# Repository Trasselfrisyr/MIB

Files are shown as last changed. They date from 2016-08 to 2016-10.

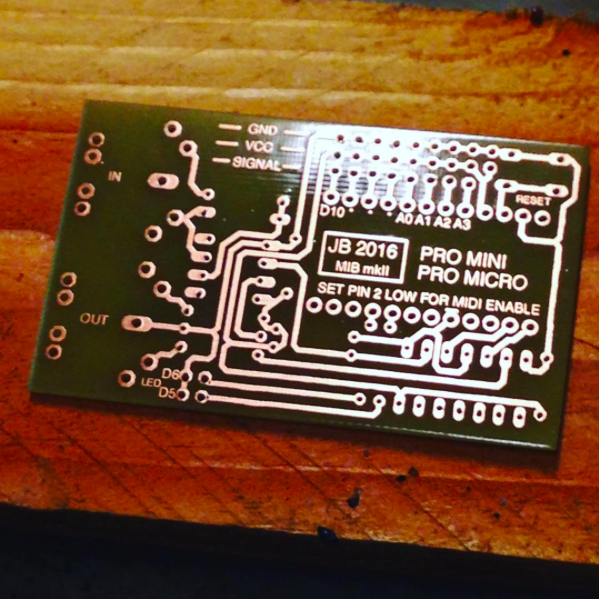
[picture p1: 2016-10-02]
MIB-board-mkII/MIBmkII-2.png

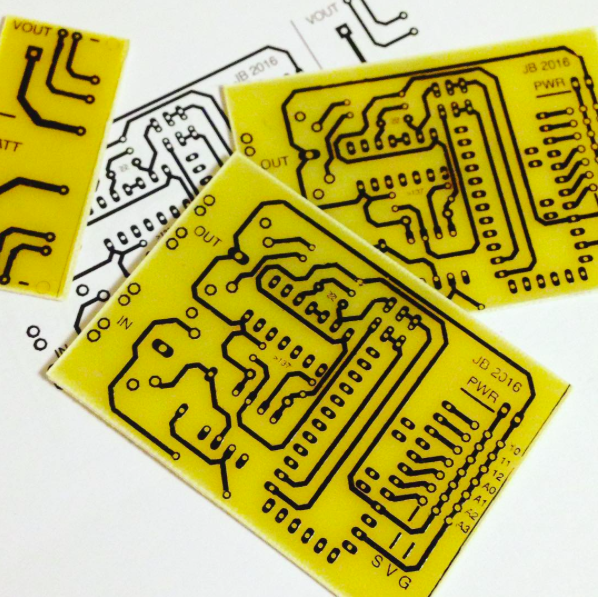
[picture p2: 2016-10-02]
MIB-board-mkI/MIBmkI-2.png

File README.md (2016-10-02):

# MIB
MIDI Injector Box, merge controller data to MIDI

Makes use of the the FortySevenEffects Arduino MIDI Library, so make sure you've got that one.

For hardware, you can build the board from plans in the MIB-board folders to use together with a Pro Mini or use any MIDI shield together with an Arduino Uno.

Breath-Injector.ino - adds breath controller data to DIN-5 MIDI from a keyboard, great for creating a MIDI melodica. For use with breath controller synth patches responding to CC#2 (breath). Can easily be changed to send other CC data like volume or mod wheel by changing the CC_Number definition in the code.

Breath-Injector-ProMicroArcore.ino - version of breath injector above, using a Pro Micro and the Arcore arduino core for USB MIDI support. This version also transmits the breath data to USB. Made for the MIB mkII board.

Volume-Injector.ino - adds volume cc data. Build your own MIDI volume pedal perhaps?

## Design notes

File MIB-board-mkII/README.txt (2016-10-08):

General board for MIB projects. MIDI in (via optocoupler)
and out (via buffer), GVS pin groups for easy connection
of potentiometers, switches and LEDs to A0-A3 and digital
pins 10 through 13 on Pro Mini. Pins 10, 15, 14 and 15 on
Pro Micro. LED connectors with resistors on pins 5 and 6.
Board power is supplied via the USB port on the Pro Micro
and by supplying regulated 5V DC power to VCC/GND if using
Pro Mini. A micro USB board connected to the dedicated pins
on the GVS strip closest to the reset button, and a USB power
adapter is a good way to do this.

Component list:

1x Arduino Pro Mini or Pro Micro (socket recommended)
1x 6N138 or 6N139 optocoupler, DIP (socket recommended)
1x 74HC125 buffer, negative enable, DIP (socket recommended)
1x 1N4148 diode, mind the orientation
2x 2K2 resistor
5x 220 ohm resistor
1x 10K resistor
2x 100nF ceramic capacitor
2x PCB mount DIN-5 MIDI PCB connector
1x Tact Switch 6x6 mm
Breakable pin headers, black, red, white/yellow for GVS
Pin headers in black and green or blue for LED connectors,
and black headers for the Arduino, to plug it into the socket
(for a snug fit agains the socket, mount the header upside
down and cut the excess off the top after soldering.)

Notes:
The board uses the 74HC125 to disconnect the MIDI circuits for
problem free reprogramming of the Pro Mini. To enable the MIDI
connection, you must set pin 2 low in the Arduino sketch.

pinMode(2,OUTPUT);
digitalWrite(2,LOW); // set pin 2 low to enable DIN MIDI

This is if you write your own code. In the MIB code projects
available on github, this is already done.

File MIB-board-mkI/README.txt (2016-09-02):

General board for MIB projects. MIDI in (via optocoupler)
and out (via optional buffer), GVS pin groups for easy connection
of potentiometers, switches and LEDs to A0-A3 and digital pins
10, 11 and 12. Optional battery power supply part with soldered
in charge/step-up board.

Component list:

1x Arduino Pro Mini
1x 6N137, 6N138 or 6N139 optocoupler, DIP (OK2)
1x 74LS14 buffer/inverter, DIP, optional (IC1)
1x 1N4148 diode, mind the orientation (D1)
2x 2K2 resistor (if 6N137, just one) (R3, R5*)
3x 220 ohm resistor (R1, R2, R4)
2x PCB mount DIN-5 MIDI PCB connector (X1, X2)
1x Slide switch DPDT (2.54 mm pin separation) (S1)
Breakable pin headers, black, red, white for GVS

Optional power circuit:

Battery holder 16340
Li-Ion battery 3.7V 16340
All-in-one charge and step-up board (r.ebay.com/uWUNOm)

VOUT +/- connects to PWR +/- of main circuit via a switch.
VIN +/- connects to panel mount power jack for 5V input.

Notes for assembling:

If the 74LS14 DIP is installed, the jumper pads marked <<>> are
left unconnected. If DIP is not installed, bridge the pads with
a jumper to connect the TX line to the output.

If the optocoupler selected for the build is a 6N137, the 2K2
resistor where PCB is marked >137 (R5) is omitted.

The slide switch on the board is for disconnecting the TX and RX
lines when uploading new programs to the Arduino. If you can't find
a DPDT switch that fits, you could go with single slide switches or
probably DIP switches too. Or jumpers.

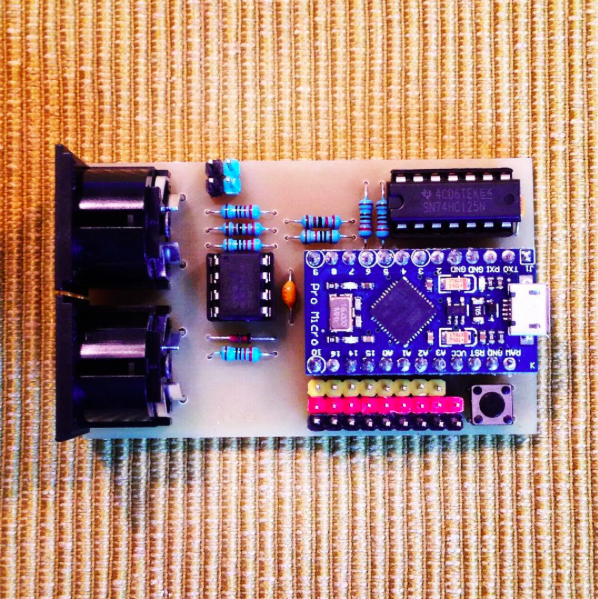
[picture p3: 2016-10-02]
MIB-board-mkII/MIBmkII-1.png

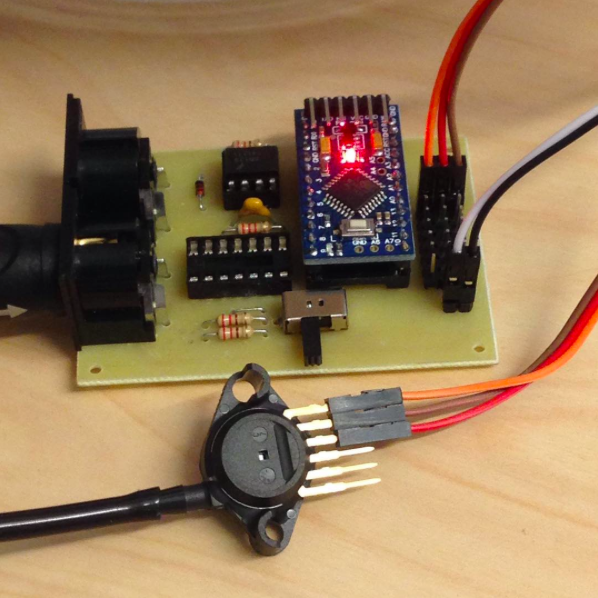
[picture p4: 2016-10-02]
MIB-board-mkI/MIBmkI-1.png

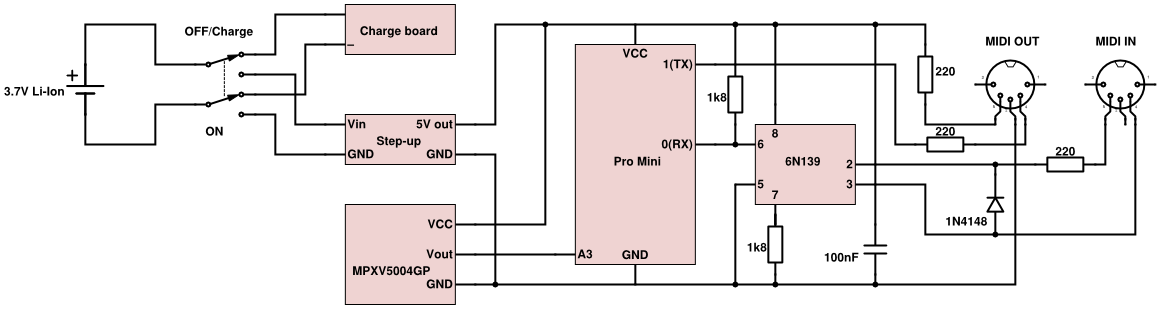
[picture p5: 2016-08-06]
Breath-Injector/Breath-Injector.png

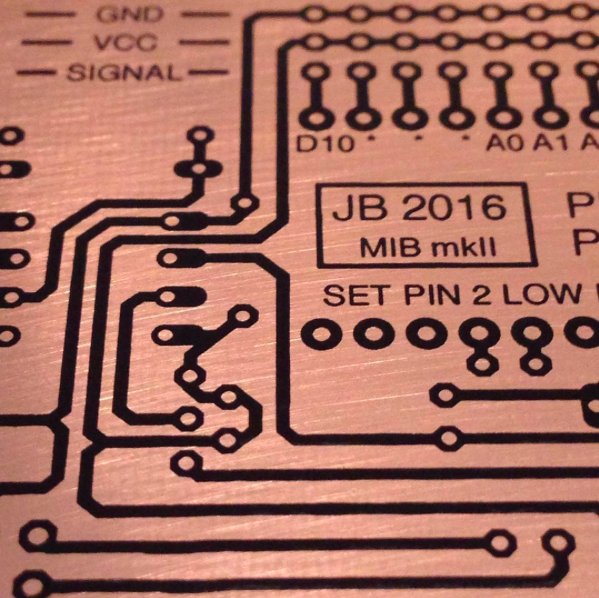
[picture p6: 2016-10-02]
MIB-board-mkII/MIBmkII-3.png

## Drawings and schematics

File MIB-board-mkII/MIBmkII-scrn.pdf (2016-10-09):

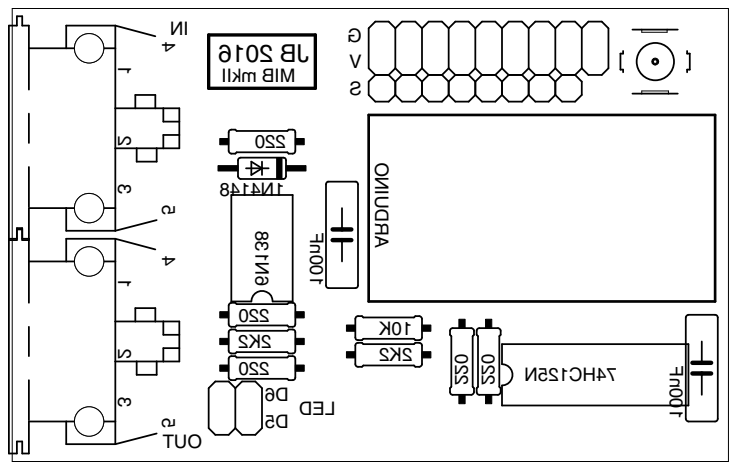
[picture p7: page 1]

II k mBI M 6102 BJDEL NI TUO 6 D5 D GVS 100nF 8414 N1 N521 CH47 6N138 022 022 022 2K2 2K2 ARDUINO K01 100nF220 2202 4 5 3 1 2 4 5 3 1

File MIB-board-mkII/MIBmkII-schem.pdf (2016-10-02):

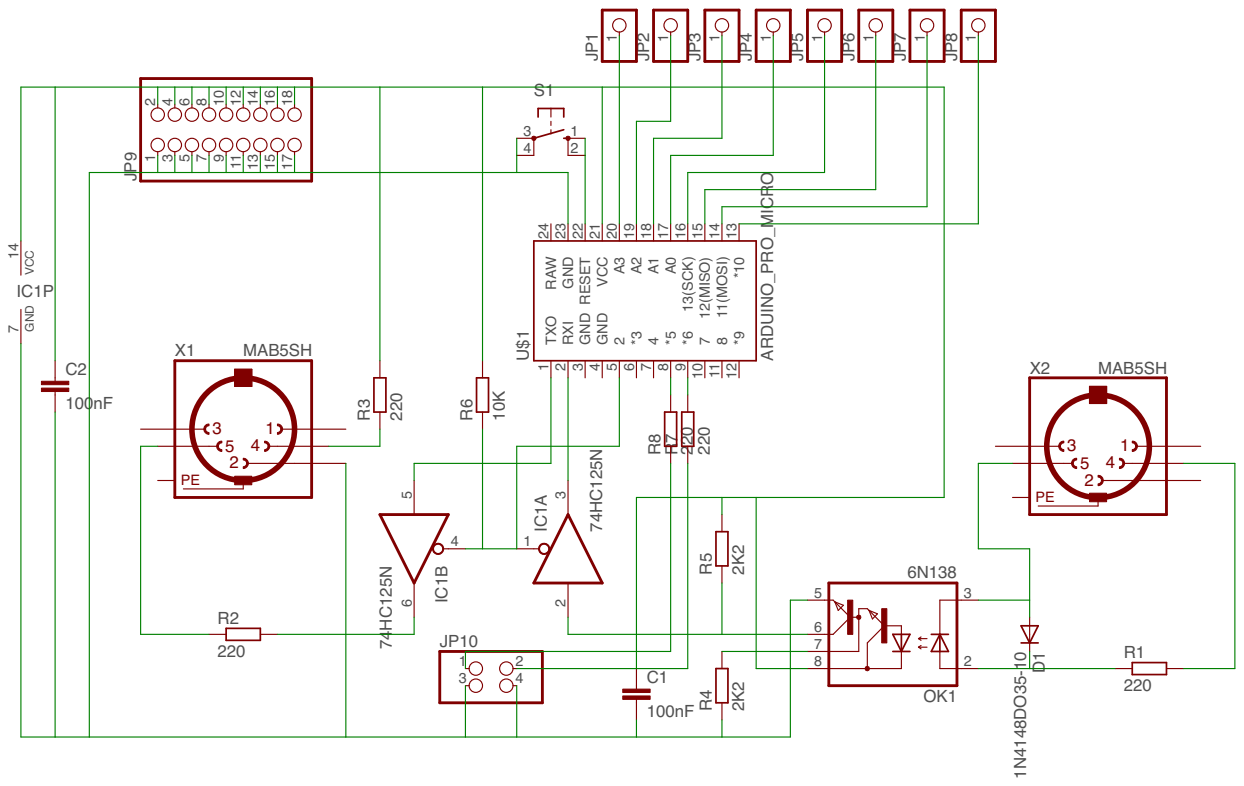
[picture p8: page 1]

ARDUINO_PRO_MICRO 74HC125N 74HC125N6N138 220 220 220 2K2 2K2 100nF 1N4148DO35-10 MAB5SH MAB5SH 10K100nF 220 220 U$12 5 *3 6 4 7 *5 8 *6 9 7 10 8 11 *9 12 *10 13 11(MOSI) 14 12(MISO) 15 13(SCK) 16 A0 17 A1 18 A2 19 A3 20 GND 4 GND 23 RAW 24 GND 3 RESET 22 RXI 2 TXO 1 VCC 21 IC1A 1 2 3 IC1B 4 5 6 IC1PGND VCC 7 14 OK1 23 7856 R1 R2 R3 R4 R5 C1 D1 X1 X2 JP11 JP21 JP31 JP41 JP51 JP61 JP71 JP81 JP91 2 3 4 5 6 7 8 9 10 11 12 13 14 15 16 17 18 R6 C2 R7 JP101 2 3 4 R8 S1 3 1 4 2 1 2 3 5 4 PE 1 2 3 5 4 PE

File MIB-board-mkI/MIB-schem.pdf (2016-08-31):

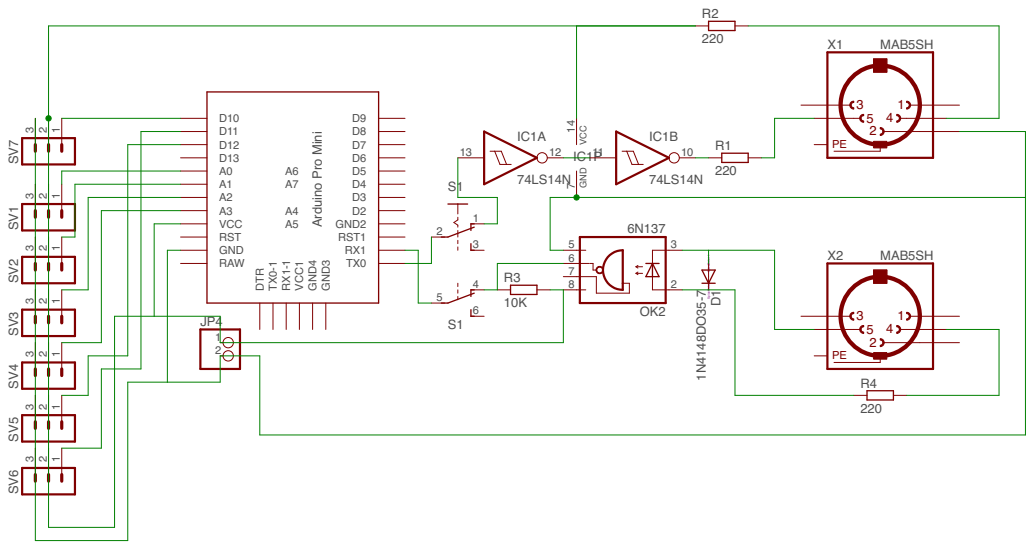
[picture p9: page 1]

SpiceOrder 1 SpiceOrder 2 Arduino Pro Mini 74LS14N 74LS14N 6N137 MAB5SH MAB5SH 220 220 10K 220 1N4148DO35-7 IC1A 13 12 IC1B 11 10 OK2 23 6857 GND3 GND4 VCC1 RX1-1 TX0-1 DTRTX0 RX1 RST1 GND2 D2 D3 D4 D5 D6 D7 D8 D9 RAW GND RST VCC A3A2A1A0D13 D12 D11 D10 A7A6A5A4 JP412 X1X2 R1 R2 R3 R4 D1 IC1PGND VCC 7 14 SV1 321 SV2 321 SV3 321 SV4 321 SV5 321 SV6 321 S1 5 64 S1 2 31 SV7 321 1 2 3 5 4 PE 1 2 3 5 4 PE

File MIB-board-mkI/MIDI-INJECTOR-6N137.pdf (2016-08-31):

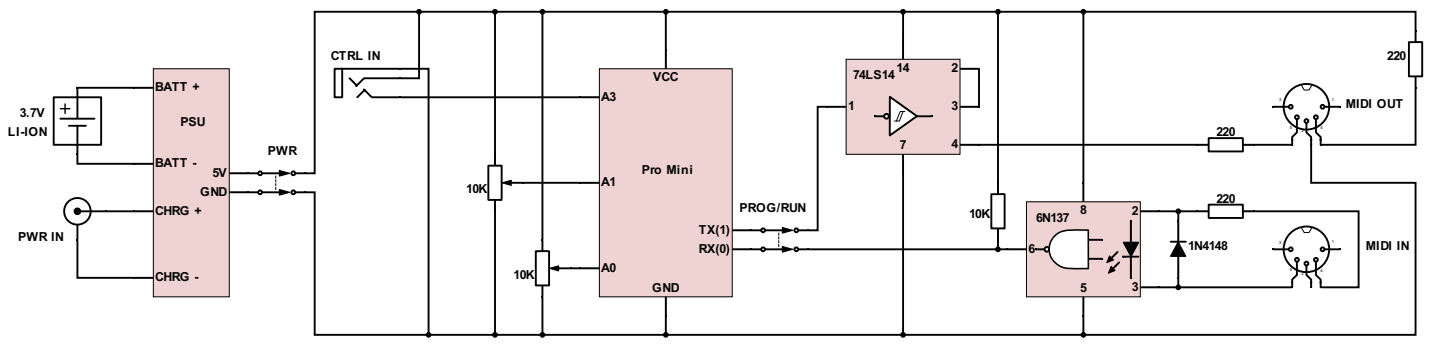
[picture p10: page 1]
MIDI IN; MIDI OUT; VCC; GND; Pro Mini; 10K PROG/RUN; CHRG -; BATT +; PSU; BATT -; CHRG +; PWR; LI-ION; PWR IN; CTRL IN

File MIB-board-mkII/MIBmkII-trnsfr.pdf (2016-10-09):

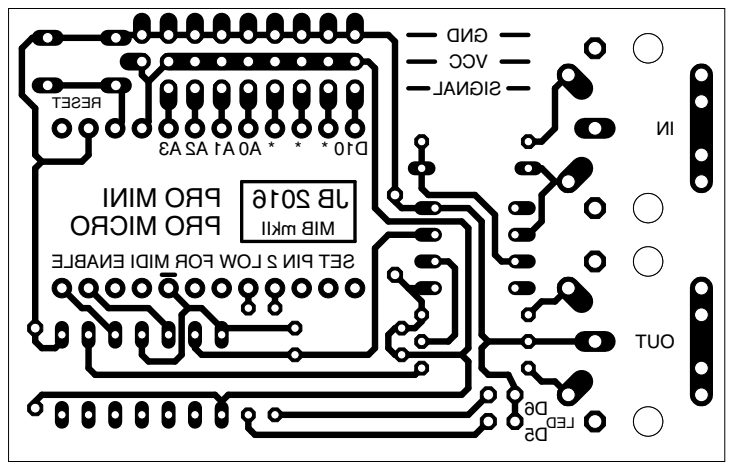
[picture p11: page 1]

ELBANEI DI M ROF WOL 2 NI P TES

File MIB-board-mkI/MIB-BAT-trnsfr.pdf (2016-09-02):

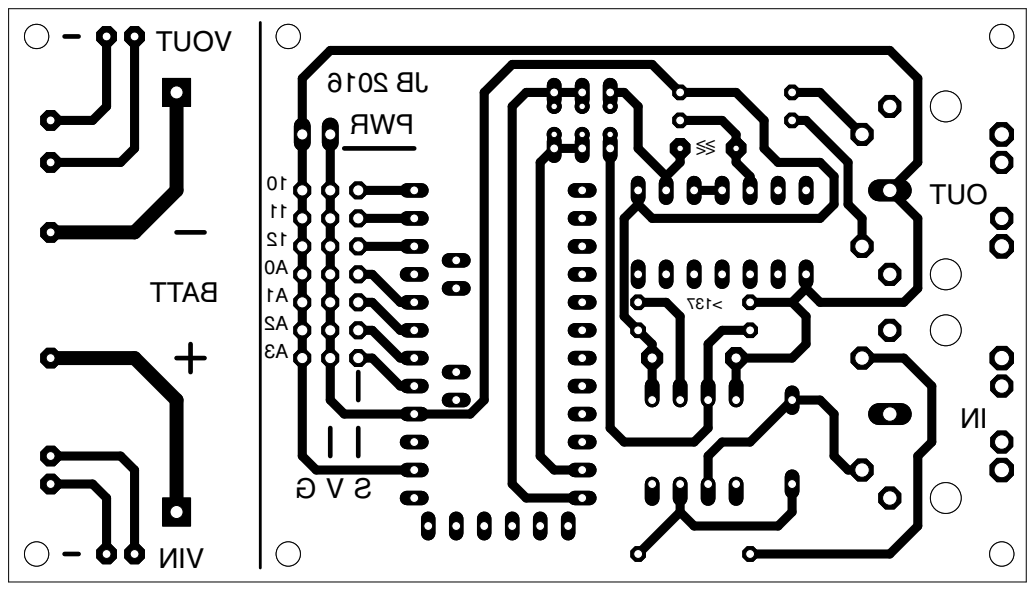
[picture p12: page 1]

TUOV NI V TTAB R WP TUONI 6102 BJ G V S 0111210A1A2A3A >><< 731>

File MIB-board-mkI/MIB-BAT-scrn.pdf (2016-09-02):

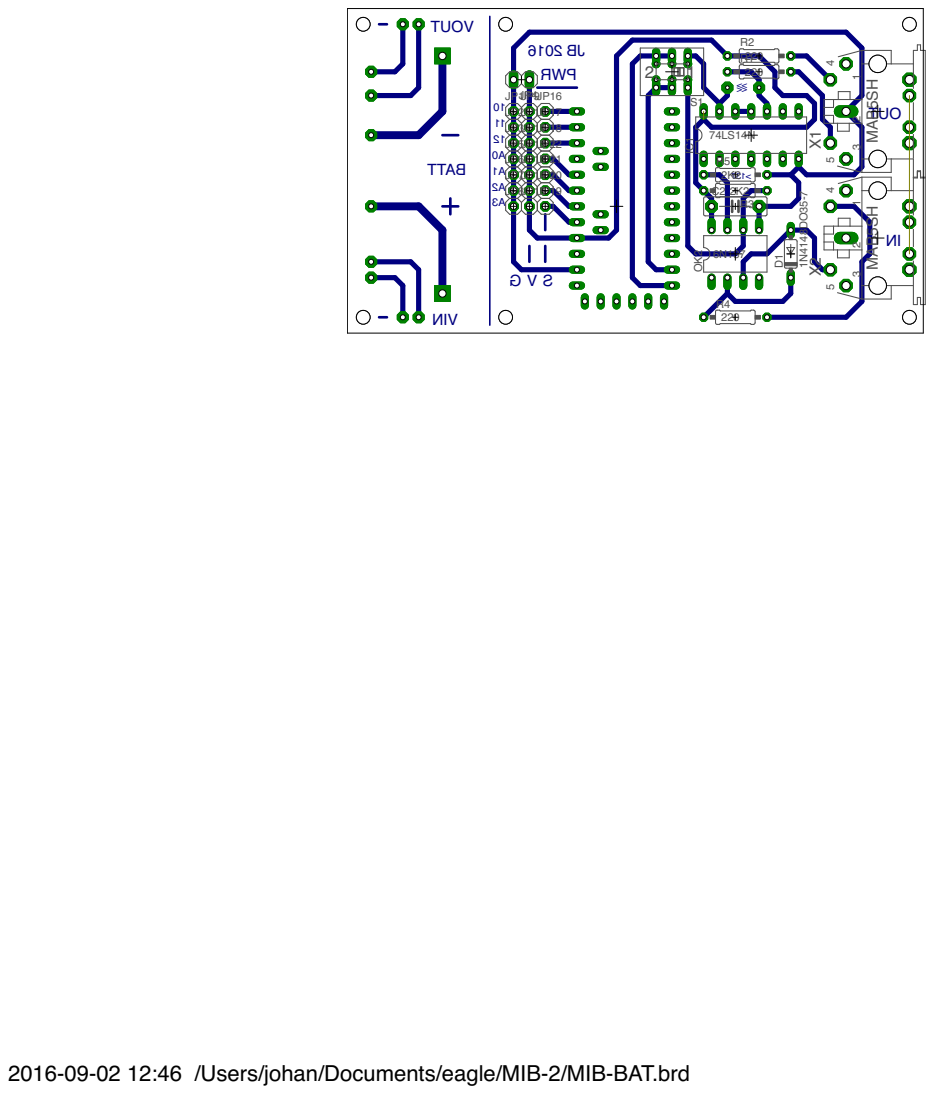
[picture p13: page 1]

2016-09-02 12:46 /Users/johan/Documents/eagle/MIB-2/MIB-BAT.brd

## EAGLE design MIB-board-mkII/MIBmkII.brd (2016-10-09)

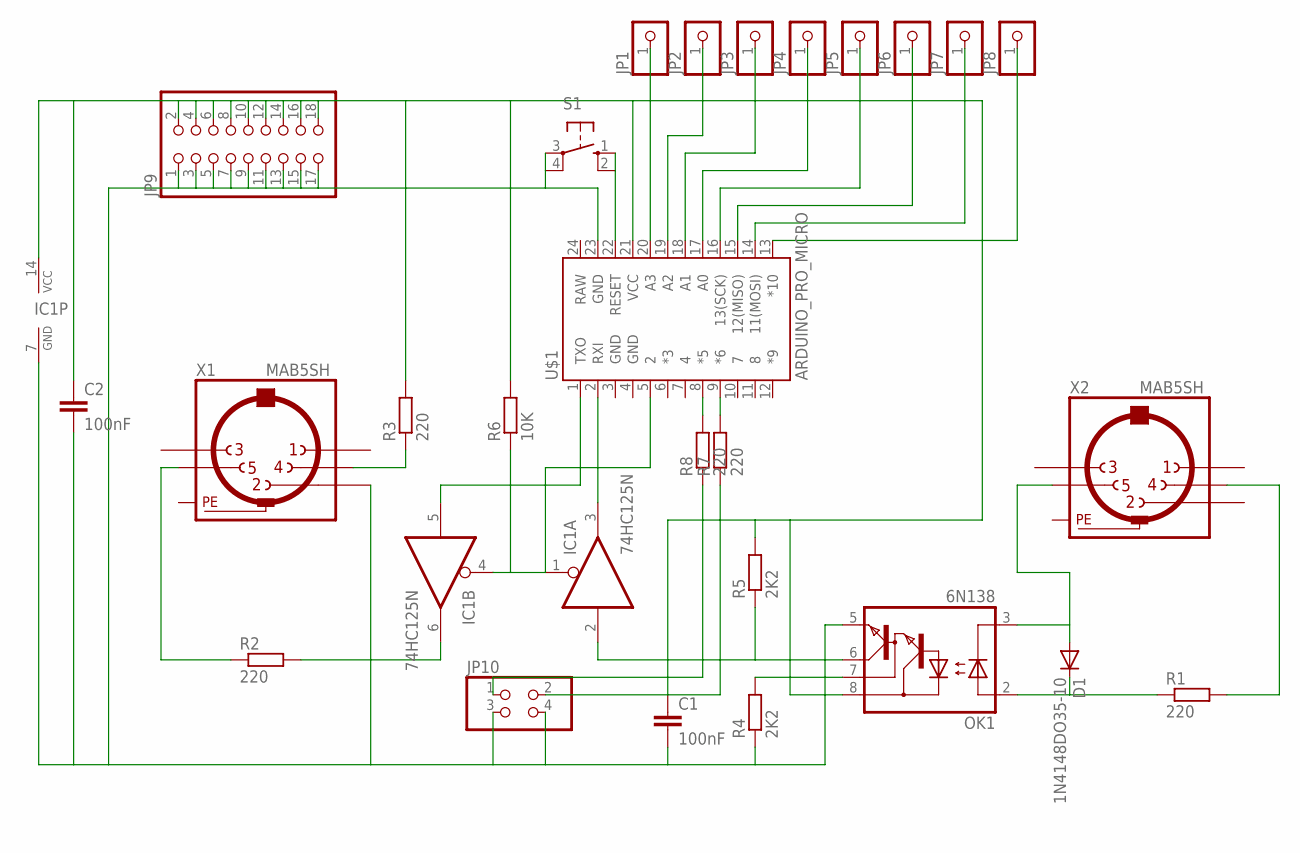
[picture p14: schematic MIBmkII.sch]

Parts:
C1, C2: 100nF; C075-032X103
D1: 1N4148DO35-10; DO35-10
IC1: 74HC125N; DIL14
JP1, JP2, JP3, JP4, JP5, JP6, JP7, JP8: PINHD-1X1; 1X01
JP9: PINHD-2X9; 2X09
JP10: PINHD-2X2; 2X02
OK1: 6N138; DIL08
R1, R2, R3, R7, R8: 220; 0207/10
R4, R5: 2K2; 0207/10
R6: 10K; 0207/10
S1: 10-XX; B3F-10XX
U$1: ARDUINO_PRO_MICRO
X1, X2: MAB5SH

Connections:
unnamed: IC1.3 (O), U$1.2 (RXI)
unnamed: IC1.5 (I), U$1.1 (TXO)
unnamed: IC1.1 (OE), IC1.4 (OE), R6.1, U$1.5 (2)
unnamed: C1.1, C2.1, IC1.14 (VCC), JP9.2, JP9.4, JP9.6, JP9.8, JP9.10, JP9.12, JP9.14, JP9.16, JP9.18, OK1.8 (VCC), R3.2, R5.2, R6.2, U$1.21 (VCC)
unnamed: C1.2, C2.2, IC1.7 (GND), JP9.1, JP9.3, JP9.5, JP9.7, JP9.9, JP9.11, JP9.13, JP9.15, JP9.17, JP10.3, JP10.4, OK1.5 (GND), R4.1, S1.3, S1.4 (P1), U$1.23 (GND), X1.2
unnamed: D1.C, OK1.2 (A), R1.1
unnamed: D1.A, OK1.3 (C), X2.5
unnamed: OK1.7 (VB), R4.2
unnamed: IC1.2 (I), OK1.6 (VO), R5.1
unnamed: R3.1, X1.4
unnamed: IC1.6 (O), R2.2
unnamed: R2.1, X1.5
unnamed: R1.2, X2.4
unnamed: JP1.1, U$1.20 (A3)
unnamed: JP2.1, U$1.19 (A2)
unnamed: JP3.1, U$1.18 (A1)
unnamed: JP4.1, U$1.17 (A0)
unnamed: JP5.1, U$1.16 (13(SCK))
unnamed: JP6.1, U$1.15 (12(MISO))
unnamed: JP7.1, U$1.14 (11(MOSI))
unnamed: JP8.1, U$1.13 (*10)
unnamed: R7.2, U$1.9 (*6)
unnamed: R8.2, U$1.8 (*5)
unnamed: JP10.1, R8.1
unnamed: JP10.2, R7.1
unnamed: S1.1 (S), S1.2 (S1), U$1.22 (RESET)
PE: X1.PE, X1.PE@ (PE), X2.PE, X2.PE@ (PE)

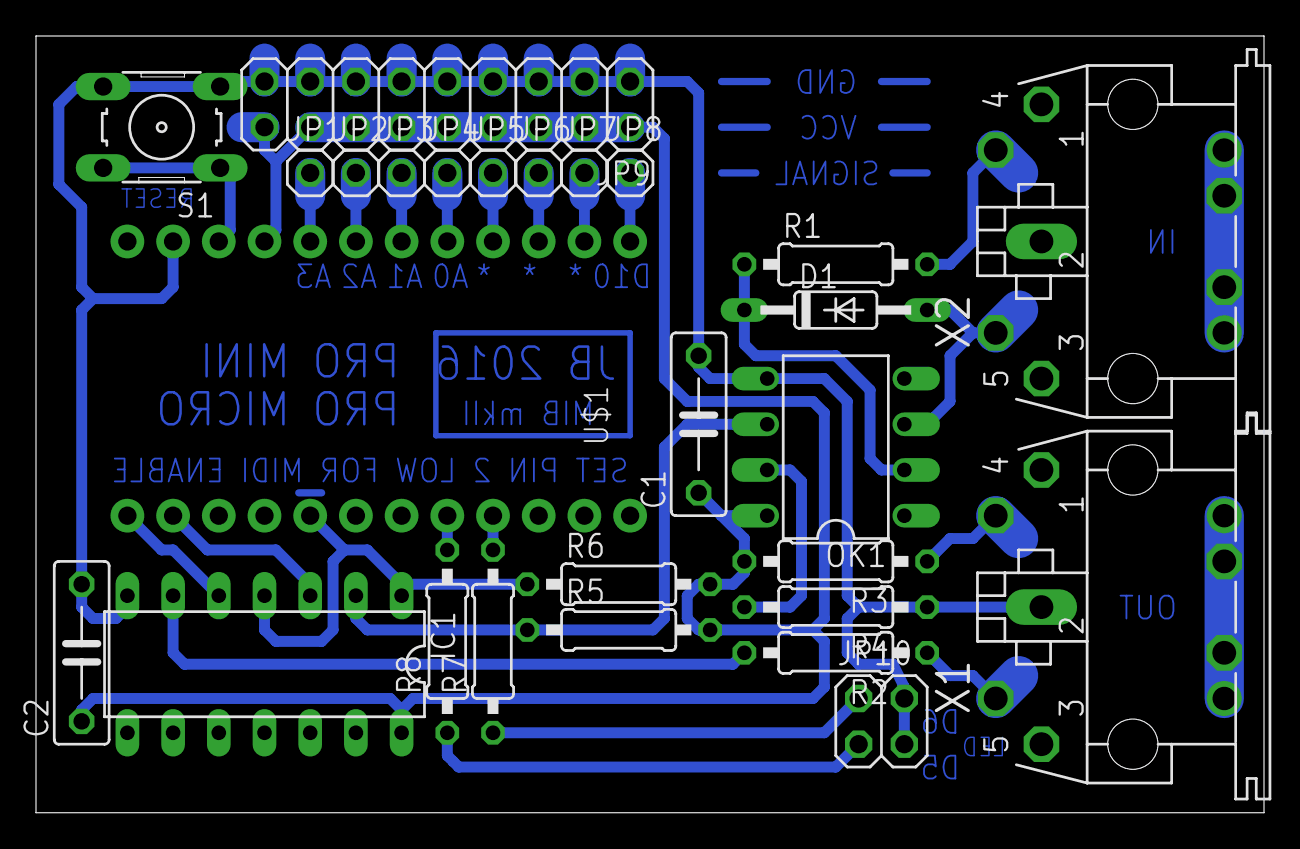
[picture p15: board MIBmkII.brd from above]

Board: 2 copper layers, 68.2 x 43.2 mm, 27 parts (0 on the bottom side), 27 nets.

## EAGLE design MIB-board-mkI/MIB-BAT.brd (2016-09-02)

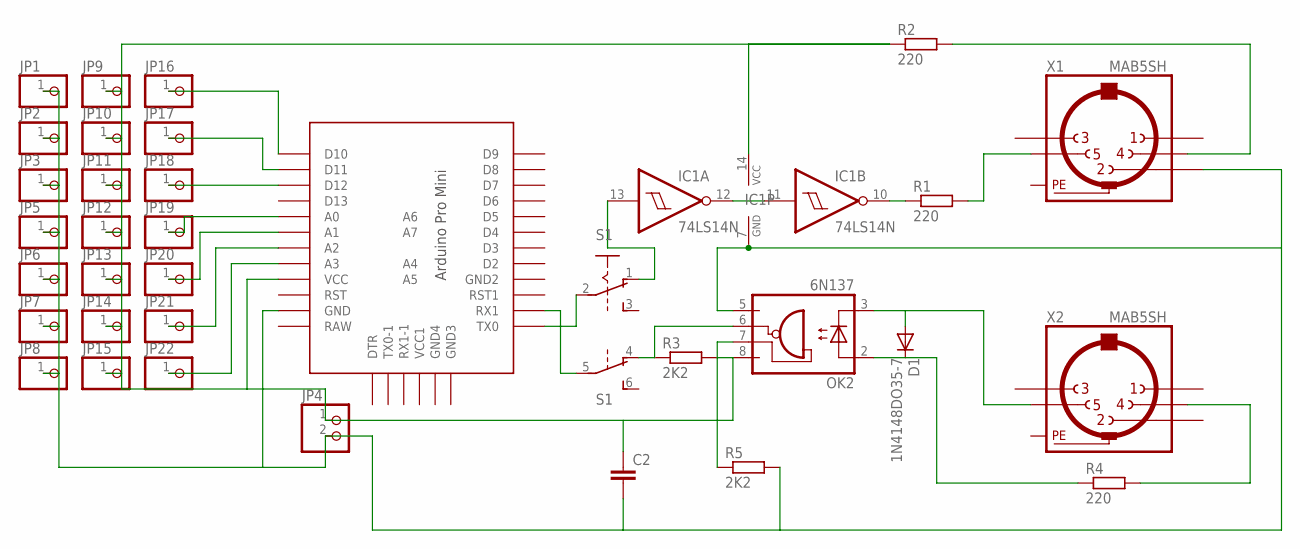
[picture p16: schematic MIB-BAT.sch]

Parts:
C2: C7.5/3; C7.5B3
D1: 1N4148DO35-7; DO35-7
IC1: 74LS14N; DIL14
JP1, JP2, JP3, JP5, JP6, JP7, JP8, JP9, JP10, JP11, JP12, JP13, JP14, JP15, JP16, JP17, JP18, JP19, JP20, JP21, JP22: PINHD-1X1; 1X01
JP4: PINHD-1X2; 1X02
OK2: 6N137; DIL08
R1, R2, R4: 220; 0207/10
R3, R5: 2K2; 0207/10
S1: A68-A31
U$1: PRO-MINI-2
X1, X2: MAB5SH

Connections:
unnamed: S1.5, U$1.RX1
unnamed: IC1.11 (I), IC1.12 (O)
unnamed: IC1.10 (O), R1.1
unnamed: D1.C, OK2.2 (A), R4.1
unnamed: R4.2, X2.4
unnamed: D1.A, OK2.3 (C), X2.5
unnamed: R1.2, X1.5
unnamed: R2.2, X1.4
unnamed: OK2.6 (VO), R3.1, S1.4 (O)
unnamed: C2.2, IC1.7 (GND), JP1.1, JP2.1, JP3.1, JP4.2, JP5.1, JP6.1, JP7.1, JP8.1, OK2.5 (GND), R5.2, U$1.GND, X1.2
unnamed: JP16.1, U$1.D10
unnamed: JP17.1, U$1.D11
unnamed: C2.1, IC1.14 (VCC), JP4.1, JP9.1, JP10.1, JP11.1, JP12.1, JP13.1, JP14.1, JP15.1, OK2.8 (VCC), R2.1, R3.2, U$1.VCC
unnamed: JP18.1, U$1.D12
unnamed: JP19.1, U$1.A0
unnamed: JP20.1, U$1.A1
unnamed: S1.2, U$1.TX0
unnamed: JP21.1, U$1.A2
unnamed: JP22.1, U$1.A3
unnamed: OK2.7 (VE), R5.1
unnamed: IC1.13 (I), S1.1 (O)
PE: X1.PE, X1.PE@ (PE), X2.PE, X2.PE@ (PE)

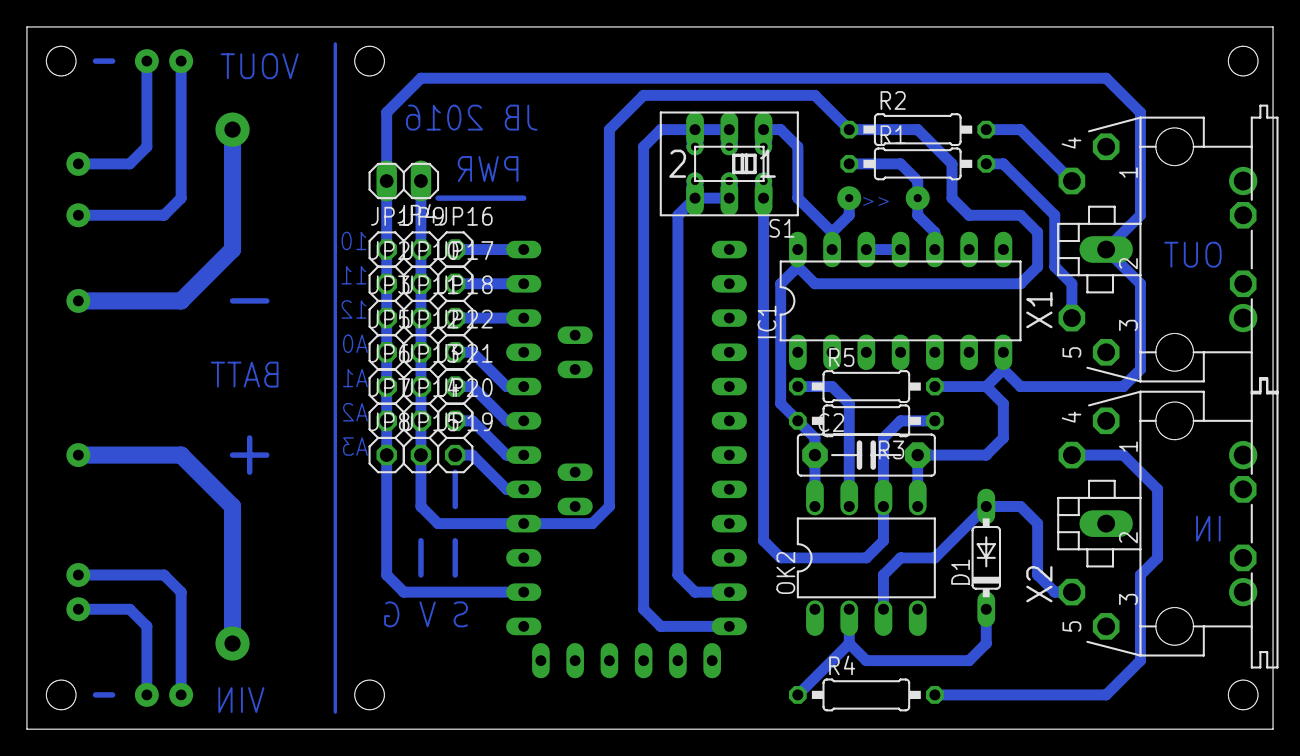
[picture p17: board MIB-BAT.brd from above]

Board: 2 copper layers, 92.4 x 52.1 mm, 35 parts (0 on the bottom side), 22 nets.

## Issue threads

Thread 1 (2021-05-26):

how to fix error   'MIDIEvent' was not declared in this scope

hadikhakbazpour, 2021-05-26:
hi
i upload file Breath-Injector-ProMicroArcore.ino to my Arduino pro micro
but not compiling successful
this is error :

C:\Users\Pro Book\Desktop\New folder (10)\MIB-master\MIB-master\Breath-Injector-ProMicroArcore\Breath-Injector-ProMicroArcore.ino: In function 'void controlChange(byte, byte, byte)':
Breath-Injector-ProMicroArcore:163:3: error: 'MIDIEvent' was not declared in this scope
   MIDIEvent event = {0x0B, 0xB0 | channel, control, value};
   ^~~~~~~~~
Breath-Injector-ProMicroArcore:164:3: error: 'MIDIUSB' was not declared in this scope
   MIDIUSB.write(event);
   ^~~~~~~
C:\Users\Pro Book\Desktop\New folder (10)\MIB-master\MIB-master\Breath-Injector-ProMicroArcore\Breath-Injector-ProMicroArcore.ino:164:3: note: suggested alternative: 'MIDI'
   MIDIUSB.write(event);
   ^~~~~~~
   MIDI
Breath-Injector-ProMicroArcore:164:17: error: 'event' was not declared in this scope
   MIDIUSB.write(event);
                 ^~~~~
C:\Users\Pro Book\Desktop\New folder (10)\MIB-master\MIB-master\Breath-Injector-ProMicroArcore\Breath-Injector-ProMicroArcore.ino: In function 'void channelAT(byte, byte)':
Breath-Injector-ProMicroArcore:168:3: error: 'MIDIEvent' was not declared in this scope
   MIDIEvent event = {0x0D, 0xD0 | channel, value};
   ^~~~~~~~~
Breath-Injector-ProMicroArcore:169:3: error: 'MIDIUSB' was not declared in this scope
   MIDIUSB.write(event);
   ^~~~~~~
C:\Users\Pro Book\Desktop\New folder (10)\MIB-master\MIB-master\Breath-Injector-ProMicroArcore\Breath-Injector-ProMicroArcore.ino:169:3: note: suggested alternative: 'MIDI'
   MIDIUSB.write(event);
   ^~~~~~~
   MIDI
Breath-Injector-ProMicroArcore:169:17: error: 'event' was not declared in this scope
   MIDIUSB.write(event);
                 ^~~~~
exit status 1
'MIDIEvent' was not declared in this scope

Trasselfrisyr, 2021-05-26:
Arcore is needed. https://github.com/rkistner/arcore

I haven't used this for quite some time, so I don't know if Arcore is compatible with current Arduino IDE versions. I guess you'll find out :)

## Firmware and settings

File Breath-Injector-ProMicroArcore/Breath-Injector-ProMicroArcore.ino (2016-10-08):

#include <MIDI.h> //FortySevenEffects Arduino MIDI Library
// Also requires Arcore Arduino core for USB MIDI

MIDI_CREATE_INSTANCE(HardwareSerial, Serial1, MIDI);

/*
NAME:                 MIB Breath Injector
WRITTEN BY:           JOHAN BERGLUND
DATE:                 2016-07-13
FILE SAVED AS:        Breath-Injector-ProMicroArcore.ino
FOR:                  Arduino Pro Micro, ATmega32U4
CLOCK:                16.00 MHz                                        
PROGRAMME FUNCTION:   Input MIDI, add breath controller data, output merged data to MIDI
                      Freescale MPXV5004GP breath sensor connected for breath control
                      Controller data also output on USB MIDI

HARDWARE NOTES:
* For the MIDI connection, attach a MIDI out Female 180 Degree 5-Pin DIN socket to Arduino.
* Socket is seen from solder tags at rear.
* 
* DIN-5 pinout for MIDI output is:                         _______ 
*    pin 2 - GND                                          /       \
*    pin 4 - 220 ohm resistor to +5V                     | 1     3 |  MIDI jack
*    pin 5 - Arduino Pin 1 (TX) via a 220 ohm resistor   |  4   5  |
*    all other pins - unconnected                         \___2___/
*    
* DIN-5 pinout for MIDI input is:                          _______ 
*    pin 2 - GND                                          /       \
*    pin 4 - 220 ohm resistor to pin 2 of 6N139          | 1     3 |  MIDI jack
*    pin 5 - to pin 3 of 6N139                           |  4   5  |
*    all other pins - unconnected                         \___2___/
*
* 6N139 optocoupler connections:
*    pin 8 - to +5V
*    pin 7 - via 1k8 ohm resistor to GND
*    pin 6 - to Arduino pin 0 (RX) via optional disconnection switch
*    pin 5 - GND
*    pin 4 - n/c
*    pin 3 - MIDI jack pin 5
*    pin 2 - MIDI jack pin 4 via 220 ohm resistor
*    pin 1 - n/c
*    also connected, a 1N4148 diode from pin 3 to pin 2, 
*    a 1k8 ohm resistor between pins 6 and 8,
*    and a 100 nF capacitor between pins 8 and 5
*      
* The Freescale MPXV5004GP pressure sensor output (V OUT) is connected to Arduino pin A3.
* Other 5V sensors can be used if thr/max values are altered or potentiometers installed.
* Examples of other sensors suitable for use: Freescale MPX5010GP, MPXV4006GP
* 
* Sensor pinout
* 1: n/c
* 2: V OUT 
* 3: GND
* 4: VCC (to 5V)    
* 5: n/c
* 6: n/c
* 7: n/c
* 8: n/c
*     
* Optional potentiometers for adjusting values for threshold and max breath are connected to
* analog inputs A0 and A1.
* 
*/



//_______________________________________________________________________________________________ DECLARATIONS


#define CC_Interval 10  // Interval for sending CC data
#define CC_Number 2     // Controller number (2=Breath, 1=Mod Wheel, 7=Volume, 11=Expression, 74=Cutoff)
#define AT_Enable 1     // Send breath as channel aftertouch (0=Off, 1=On, 2=Exclusively)
#define POT_Avail 1     // Potentiometers installed at A0 and A1?

unsigned long ccSendTime = 0L;     // The last time we sent CC values

int pressureSensor=0;// pressure data from breath sensor, for midi breath cc and breath threshold checks
byte itsOn=0;        // keep track and make sure we send CC with 0 value when off threshold
int ON_Thr=350;      // Set threshold level before switching ON (Value used if no pots installed. MPXV5004GP->350, MPX5010GP->40)
int breath_max=1023; // Upper limit for pressure (Value used if no pots installed. MPXV5004GP->1023, MPX5010GP->300)

int x;
byte LedPin=5;    // select the pin for the activity LED
byte PwrLedPin=6; // select the pin for the power LED
byte channel=1;    // MIDI channel (1-16)
float smooth=0.05; // smoothing value

//_______________________________________________________________________________________________ SETUP

void setup() {
  pinMode(LedPin,OUTPUT);
  pinMode(2,OUTPUT);
  digitalWrite(2,LOW); // set pin 2 low to enable DIN MIDI on MIB mkII board
  
  MIDI.begin(channel);
  
  for (x=1; x<=255; x++){  // Fade in power LED for extra class and swag
    analogWrite( PwrLedPin, x );
    delay(10);
  }

}


//_______________________________________________________________________________________________ MAIN LOOP

void loop() {
  if (POT_Avail) {
    ON_Thr=map(analogRead(A0),0,1023,0,850);  // set threshold value with potentiometer on A0
    breath_max=map(analogRead(A1),0,1023,150,1023); // set max value with potentiometer on A1
    if ((ON_Thr+127) > breath_max){            // make sure max value always has a minimum offset from thr
      breath_max=ON_Thr+127;
    }
  }
  pressureSensor=pressureSensor*(1-smooth)+analogRead(A3)*smooth;   // get pressure sensor data, do some smoothing
  MIDI.read();
  if (millis() - ccSendTime > CC_Interval) {  // is it time for sending breath data?
   if (pressureSensor >= ON_Thr) {            // if we are over the threshold, send breath
     breath();    
     itsOn=1;
    } else if (itsOn) {                       // we have just gone below threshold, so send zero value
     breathOff();
     itsOn=0;
    }
    ccSendTime = millis();                   // reset cc timer
  }  
}

//_______________________________________________________________________________________________ FUNCTIONS

void breath(){
  int breathCC;
  breathCC = map(constrain(pressureSensor,ON_Thr,breath_max),ON_Thr,breath_max,1,127);
  if (AT_Enable != 2) {
    MIDI.sendControlChange(CC_Number, breathCC, channel);
    controlChange(channel-1, CC_Number, breathCC);
  }
  if (AT_Enable) {
    MIDI.sendAfterTouch(breathCC, channel);
    channelAT(channel-1, breathCC);
  }
  analogWrite(LedPin, breathCC);
}

//***********************************************************

void breathOff(){
  if (AT_Enable != 2) {
    MIDI.sendControlChange(CC_Number, 0, channel);
    controlChange(channel-1, CC_Number, 0);
  }
  if (AT_Enable) {
    MIDI.sendAfterTouch(0, channel);
    channelAT(channel-1, 0);
  }
  digitalWrite(LedPin, LOW);
}

//***********************************************************
// Arcore MIDI functions

void controlChange(byte channel, byte control, byte value) {
  MIDIEvent event = {0x0B, 0xB0 | channel, control, value};
  MIDIUSB.write(event);
}

void channelAT(byte channel, byte value) {
  MIDIEvent event = {0x0D, 0xD0 | channel, value};
  MIDIUSB.write(event);
}

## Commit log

2016-07-13 Added untested code and schematic.
2016-07-13 Cleanup and making sure CC value 0 is sent when off threshold. Removed DIP switches for channel selection. New schematic.
2016-08-03 Changed sensor to MPXV5004GP and modified values accordingly.
2016-08-06 Updated schematic image
2016-08-31 Added schematics and PCB transfer files for making a MIDI circuit board for the MIB projects. Runs on regulated 5V input.
    [MIB.brd, MIB.sch]
2016-08-31 Weblink to recommended power board.
2016-09-01 Better version board with optional battery power supply
    [MIB-BAT.brd, MIB-BAT.sch]
2016-09-02 New PCB layout enabling choice of optocoupler and makes the buffer optional.
    [MIB-BAT.brd, MIB-BAT.sch]
2016-10-02 New mkII board design added. Breath injector code for Pro Micro and Arcore added.
    [MIB-BAT.brd, MIB-BAT.sch, MIBmkII.brd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]
2016-10-02 Added pictures and schematics.
2016-10-08 Updated code with pin 2 MIDI enable for MIB mkII board
2016-10-08 Better silkscreen, smaller pdf area for easier multiple prints per page
2016-10-09 Corrected labeling on silkscreen. Increased size of some pads and traces.
    [MIBmkII.brd]

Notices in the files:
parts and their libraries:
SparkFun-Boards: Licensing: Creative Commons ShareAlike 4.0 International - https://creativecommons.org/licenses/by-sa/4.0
